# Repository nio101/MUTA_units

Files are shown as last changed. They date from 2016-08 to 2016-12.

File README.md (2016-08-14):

# MUTA_units
An open source home automation solution for hobbyists and makers

## customizing the firmwares before flashing

In the **MPLAB IPE**, activate *Setting/advanced mode*, open the firmware/.hex file you want to customize, and then select *View/show memory*.
On the *Operate* tab, you'll have a memory view window. Skip to the end of the memory and you fill view the constants you can edit inline before flashing:
* static_encryption_key @ 0x01FFEC (8 bytes)
* make/model @ 0x01FFF4 (2 bytes)
* unit_uid @ 0x01FFF6 (2 bytes)
You can then use the *view/fill memory* dialog to modify those values and check the modifications on the memory view afterwards.
*important: due to Endianness, the first and second bytes are swapped for each memory value, so you should input for example 0x0201@0x01FFF4 to get a 01 model and a 02 make*
*remark: This manual process could be done in a much easier way with the hexmate util, but my first tries weren't successfull and I couldn't spend more time on it.*

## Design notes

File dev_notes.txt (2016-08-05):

questions à adresser...

* quand un operateur disconnecte et revient, un scout peut lui envoyer un message sans reinit, mais l'operateur ne peut pas lui répondre...
=> si un autre scout utilise la même adresse dans le nouveau réseau que le scout qui est encore dans l'ancien, il va se fait passer
pour lui -> toujours transmettre l'UID et l'utiliser comme réel identifiant
L'adresse locale est juste stockée pour pouvoir communiquer avec lui, mais on transmet aussi en retour l'UID et chaque scout vérifie que c'est bien pour lui avant d'interpréter.
résumé: utiliser l'UID pour valider les messages dans les deux sens, la short address ne sert que d'alias
=> est-ce qu'on ne pourrait pas directement utiliser la long address[4]==myMODEL+myUID ?
ce serait l'idéal...
=> UnicastAddress an long adress ?

PacketLQI... == qualité, à exploiter, en complément de RSSI==puissance du signal

implémenter une commande au niveau du PAN qui permet de dumper le tableau des connections et checker les infos disponibles
dans le cas normal + cas d'erreurs (ex.: PAN remonte le réseau et recoit un message d'un scout toujours dans l'ancien réseau)

est-ce que active scan result contient aussi des end devices ? on dirait puisqu'il y a l'option sleep dans les flags de résultat...
faire le test (il faut 2 scouts!)
Si oui, limiter la connection aux devices PAN/coordinators

Implémenter un scout sur l'ancien proto d'opérateur et un PAN sur le nouveau...
=> dumper les tables de scan et les tables de connection
pui ajouter 2 coordinators (cartes protos) et le (vrai) scout
=> check tables et des différents cas/tests déco/reco, etç...

Mettre un ConnectionMode(DISABLE_ALL_CONN) sur les scouts et end devices
=> ils ne répondront pas aux active scan et aux demandes de connection

------------------------------------------------------------------------------
Liste des fonctions de l'API OUIOUI:
====================================
bool MiApp_ProtocolInit(FALSE) // false for networkfreezer/nvm use

MiApp_NoiseDetection	=> scan for noise/nergy or porteuse (PAN)

MiApp_SearchConnection => scan for existing networks

bool MiApp_SetChannel(channel)

MiApp_ConnectionMode => if device responding to connections/active scans ?

bool MiApp_StartConnection(START_CONN_DIRECT, 0,0)	// start a network

MiApp_EstablishConnection(ScanIndex, MODE_DIRECT)	// join a network through a PAN or coordinator

MiApp_FlushTx() => vide le buffer d'envoi / reset
MiApp_WriteData(byte) => ajoute un octet utilise au message à envoyer

* 3 choix pour l'envoi:
- broadcast => all devices receive the message
- unicast with shortaddress
- unicast with longaddress

MiApp_Broadcast(Sec_enabled)
MiApp_UnicastConnection(ConnectionIndex, Sec_enabled)
MiApp_UnicastAddress(*address, bool IsLongAddress, bool Sec_enabled)

MiApp_MessageAvailable() -> test if new message has been received

MiApp_DiscardMessage() -> flush the received message

MiApp_RemoveConnection(ConnectionIndex)

MiApp_TransceiverPowerStat(POWER_STATE_SLEEP/POWER_STATE_WAKEUP) -> put the MRF89XA to sleep/wake it up

// channel hopping / frequency agility
// prevent noise problems + hack is more difficult

MiApp_InitChannelHopping(channelmap)

for sleeping devices which didn't see it:
MiApp_ResyncConnection(connections index, channelmap)
------------------------------------------------------------------------------
SCAN CONNECTIONS RESULT:

    typedef struct
    {
        uint8_t		Channel;                        // Operating Channel of the PAN
        uint8_t        Address[MY_ADDRESS_LENGTH];     // Responding device address
        API_UINT16_UNION    PANID;                          // PAN Identifier
        uint8_t       RSSIValue;                      // RSSI value for the response
        uint8_t        LQIValue;                       // LQI value for the response
        union
        {
            uint8_t        Val;
            struct
            {
                uint8_t    Role:		2;              // Role of the responding device in the PAN
                uint8_t    Sleep:		1;              // Whether the responding device goes to sleep when idle
                uint8_t    SecurityEn:	1;              // Whether the responding device is capable of securing the data
                uint8_t    RepeatEn:	1;              // Whether the responding device allow repeat
                uint8_t    AllowJoin:	1;              // Whether the responding device allows other device to join
                uint8_t    Direct:		1;              // Whether the responding device in radio range or through a repeater
                uint8_t    altSrcAddr: 1;              // Whether the Address is alternative network address or permanent address
            } bits;
        } Capability;
    } ACTIVE_SCAN_RESULT;

    extern ACTIVE_SCAN_RESULT ActiveScanResults[ACTIVE_SCAN_RESULT_SIZE];
------------------------------------------------------------------------------
CONNECTIONS:

    typedef union __CONNECTION_STATUS
    {
        uint8_t Val;
        struct _CONNECTION_STAUTS_bits
        {
            uint8_t RXOnWhenIdle       :1;     //1 = transceiver always on, 0 = transceiver sleeps when idle
            uint8_t directConnection   :1;     //1 = can talk to this device directly, 0 = must route to this device
            uint8_t longAddressValid   :1;     //1 = long address valid, 0 = long address unknown
            uint8_t shortAddressValid  :1;     //1 = short address valid, 0 = short address unknown
            uint8_t FinishJoin         :1;     //1 = already finish joining procedure, 0 = in the process of join
            uint8_t isFamily           :1;     //1 = family member (parent/child), 0 = not family
            uint8_t filler             :1;
            uint8_t isValid            :1;     //1 = this entry is valid, 0 = this entry is not valid
        } bits;   
    } CONNECTION_STATUS;

typedef struct __CONNECTION_ENTRY
    {
            API_UINT16_UNION    PANID;                      // PAN Identifier of the peer device.
            API_UINT16_UNION    AltAddress;                 // Alternative address of the peer device. - SHORT ADDRESS

        uint8_t        Address[MY_ADDRESS_LENGTH];     // Permanent address of peer device - LONG ADDRESS
        
        CONNECTION_STATUS status;
        
    } CONNECTION_ENTRY;

CONNECTION_ENTRY    ConnectionTable[CONNECTION_SIZE];
------------------------------------------------------------------------------
MESSAGE RECU:

typedef struct
    {
        union
        {
            uint8_t Val;
            struct
            {
                uint8_t		broadcast:  2;      // 1: broadcast message
                uint8_t		ackReq:     1;      // 1: sender request acknowledgement in MAC.
                uint8_t		secEn:      1;      // 1: application payload has been secured
                uint8_t		repeat:     1;      // 1: message received through a repeater
                uint8_t		command:    1;      // 1: message is a command frame
                uint8_t        srcPrsnt:   1;      // 1: source address present in the packet
                uint8_t        altSrcAddr: 1;      // 1: source address is alternative network address
            } bits;
        }  flags;

        API_UINT16_UNION    SourcePANID;                // PAN Identifier of the sender
        uint8_t		*SourceAddress;             // pointer to the source address
        uint8_t		*Payload;                   // pointer to the application payload
        uint8_t		PayloadSize;                // application payload length
        uint8_t		PacketRSSI;                 // RSSI value of the receive message
        uint8_t 	PacketLQI;                  // LQI value of the received message

    } RECEIVED_MESSAGE;
------------------------------------------------------------------------------
operator:
=========
1) uint8_t BestChannel = MiApp_NoiseDetection(BASIC_CHANNELS_TEST, 14, NOISE_DETECT_ENERGY, &noise_level);
2) MiApp_SetChannel(BestChannel)
3) MiApp_ConnectionMode(ENABLE_ALL_CONN);
4) MiApp_StartConnection(START_CONN_DIRECT, 0, 0);
5) if(MiApp_MessageAvailable())
        {	... }
6) MiApp_UnicastAddress(&shortaddress, false, false)
        	
scout:
======
1) scanresult = MiApp_SearchConnection(14, COMPLETE_CHANNELS_TEST);
2) MiApp_EstablishConnection(best_candidate, CONN_MODE_DIRECT);
3) MiApp_UnicastAddress(&shortaddress, false, false)
4) if(MiApp_MessageAvailable())
            {
                // message received
                //if(rxMessage.Payload[0] == 0x13 && rxMessage.Payload[1] == 0x37)
                counter = rxMessage.Payload[2];
                MiApp_DiscardMessage();
            	break;
            }

repeater:
=========

1) MiApp_SearchConnection(14, COMPLETE_CHANNELS_TEST);
2) MiApp_ConnectionMode(ENABLE_ALL_CONN);
3) MiApp_EstablishConnection(j, CONN_MODE_DIRECT);
4) if(MiApp_MessageAvailable())
		MiApp_DiscardMessage();

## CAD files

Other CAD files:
src/18F27J53_op_basecamp/dev_18F27J53_operator_basecamp.X/dist/18F27J53/production/dev_18F27J53_operator_basecamp.X.production.obj
src/18F27J53_op_basecamp/dev_18F27J53_operator_basecamp.X/l.obj
src/18F27J53_op_relay/dev_18F27J53_operator_relay.X/dist/16F27J53/production/tests_conso.X.production.obj
src/18F27J53_op_relay/dev_18F27J53_operator_relay.X/dist/18F27J53/production/dev_18F27J53_operator_relay.X.production.obj
src/18F27J53_op_relay/dev_18F27J53_operator_relay.X/l.obj
src/18F27J53_scout_dormant/dev_18F27J53_scout_dormant.X/dist/18F27J53/production/dev_18F27J53_scout_dormant.X.production.obj
src/18F27J53_scout_dormant/dev_18F27J53_scout_dormant.X/l.obj

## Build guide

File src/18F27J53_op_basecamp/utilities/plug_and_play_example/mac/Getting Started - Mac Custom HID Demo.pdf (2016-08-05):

# Mac Custom HID Demo

### Contents

Xcode and Objective-C

Interface Builder

HID Framework

Application Overview

Graphical User Interface Overview

Common Pitfalls

### Xcode and Objective-C

The Mac Custom HID Demo application was created using Xcode, Apple’s IDE that comes pre-packaged with Mac OS X operating systems. In this example, the Cocoa application programming interface (API) is used. Cocoa is one of Apple’s APIs available for Mac OS X, and uses the Objective-C programming language. Objective-C is an object-oriented programming language that is built on top of C that is used primarily by Apple. For more information on Objective-C and a good starting point for beginners, check out Apple’s guide to Learning Objective-C. (http://developer.apple.com/library/ios/)

### Interface Builder

The Interface Builder application is part of Xcode, and also comes pre-packaged with MAC OS X operating systems. It is used to design graphical user interfaces (GUIs), and was used to design the GUI in this example. A simple step-by-step tutorial showing how to use Xcode with the Interface Builder is available in the Mac OS X Reference Library called the Cocoa Application Tutorial. (http://developer.apple.com/library/mac/)

### HID Framework

For HID class USB communication between a Mac and a connected device, Cocoa uses an API called the HID Manager that is part of the I/O Kit framework. In order to use the HID Manager in your project, the I/O Kit framework needs to be added. Follow these steps to do this:

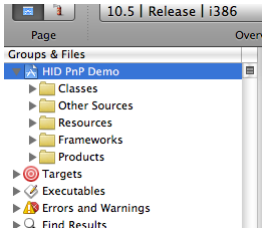
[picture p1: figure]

1. After creating your project, expand your project in the “Groups & Files” panel to show the Frameworks subfolder.

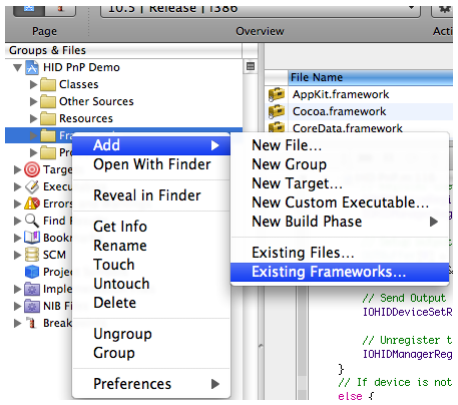
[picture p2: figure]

2. Right click on the Frameworks subfolder (command-click) and select Add > Existing Frameworks…

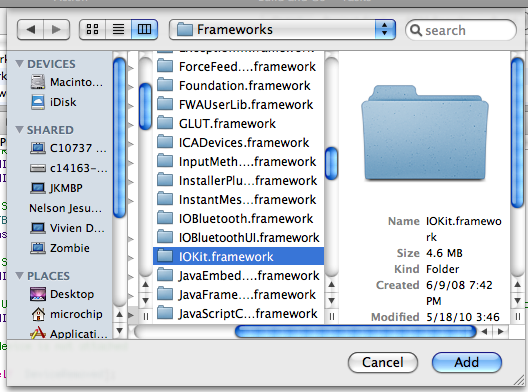
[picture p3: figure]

3. Scroll down and select IOKit.framework and click the Add button.

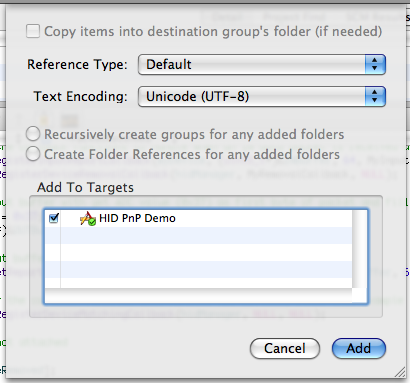
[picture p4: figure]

4. A verification window will be shown. Click the Add button again.

Now the HID Manager can be used in your project. To make the functions within the HID Manager API available make sure to use #import. #import is similar to #include, but ensures a header is included only once in a source file. For this example, the HID_PnP class uses the following:

#import <IOKit/hid/IOHIDManager.h>

This API is implemented in C, but because Objective-C is a strict superset of C, the API can be used interchangeably within Objective-C code. The HID Manager handles all enumerated HID class devices and allows access to their properties, notification for when a new device is enumerated or an existing devices is removed, and communication between host and device. For more detailed information about the HID Manager, both Technical Note TN2187 (http://developer.apple.com/library/mac/#technotes/tn2007/tn2187.html) and the HID Class Device Interface Guide (http://developer.apple.com/library/mac/#documentation/DeviceDrivers/Conceptual/HID/intro/intro.html) are good sources.

### Application Overview

Overall, the same GUI and functionality is used as Microchip’s Plug and Play example for Windows. The pushbutton status and potentiometer values are transmitted from the device to the host, and when the toggle LED(s) button is pressed in the app window, the LEDs on the device are toggled. The demo also supports hot plugging the device and detects when the device is removed.

Because the demo is written in a different language and is on a different operating system, the code layout is not exactly the same. This is a brief overview of how the application works. There are two objective-C classes that behave similarly to a C++ class or Java class, the HID_PnP class and the DemoApp class.

The HID_PnP class handles the communication with the Custom HID Device. There is an instance of a HID Manager as well as an instance of a HID Device within the class. When a device is attached, the HID Device instance holds the information about that device. The HID Manager is always running and is initialized with a few C callback functions for when a device is attached, removed, or when it sends data. These functions are called when one of these events occurs. Otherwise it returns to the run loop that is running the application.

The DemoApp class handles the application window created in the interface builder. It updates what is seen in the window depending on what information is sent from the device. There is an object of the HID_PnP class that is part of the DemoApp class. This object handles the communication and is polled every 15 ms (~60 Hz) by the DemoApp Class to update its window. It also notifies the HID_PnP object when the Toggle LED(s) button has been pressed.

The run loop for the entire application is shared by HID communication, GUI updates, and the button in the GUI window. This means that all of these are in one thread, which is different from the windows application. The windows application has two threads, one for updating the GUI and waiting for a button press, and another for HID communication. The windows thread that handles the HID communication communicates asynchronously with the device. This means that the functions called are blocking, so while the host is communicating the device, any other code is halted from executing on the same thread. For the mac, the communication is synchronous, which means that the functions are non-blocking and perform similar to an interrupt on a microcontroller. This means that the application can return to the run loop and perform other tasks such as updating the gui while it waits for the device to respond to the host.

### Graphical User Interface Overview

Below is what the application window looks like when the device is disconnected. The progress bar and labels are greyed out, the toggle LED button is disabled, the text box at the top states that the device is not attached, and the pushbutton status is unknown.

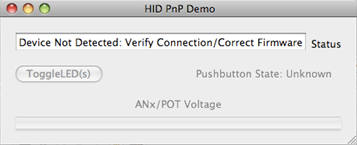
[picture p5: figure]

Next is what the application window looks like when the device is connected. The progress bar begins to show the value of the potentiometer, the labels are no longer greyed out, the toggle LED button is no longer disabled, the text box at the top states that the device is attached, and the pushbutton state is either pressed or unpressed.

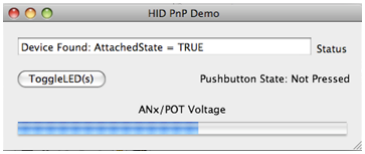
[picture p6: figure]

### Common Pitfalls

Mixing Objective-C with C
There are some common pitfalls that one might run into while developing USB code for the mac. For instance, if an application GUI is preferred, then the interface builder is the easiest way to create the GUI. In order to use the interface builder, objective-C should be used. However, some APIs are in C or C++, which means that mixing the two languages is required. It is possible to have C functions inside of an objective C class.

This example shows how that is possible. The C callback functions for the HID Manager are part of the HID_PnP class. However, since they are C functions, they do not have access to the variables inside of the class nor can they have objects including the instance of the HID_PnP class which is referred to as “self” inside of the class. Because “self” can’t be used, accessing the class methods is difficult (which is called sending a message in Objective-C). To go around this, a self referencing void pointer is created as a global variable in the source file of the HID_PnP class. This pointer points to the instance of the class itself in the init method – the class initialization function for HID_PnP. Because of Objective-C’s ability for dynamic typing (see Objective-C overview), the void pointer can act as the self reference and can access the class’s methods.

Additionally, because some functions are in C, they are unable to take objects as arguments. To go around this, there are definitions of structs within the API that are the same size as objects that are needed as arguments. So, if writing in objective-C type-casting can be used to go between objects and structs.

Mouse Click Events
For each thread used in an application there is a run loop. A run loop is (usually) an infinite loop that runs certain actions over and over again. However, if one of these actions is blocking (meaning it waits for an event to complete before returning to the run loop) then it can create a delay for other actions within the same run loop. The usual solution to this problem is to separate the blocking actions into separate threads. This is not always the case, though.

A mouse click event is when a mouse click occurs in the window that can be blocking to the application, for example clicking and holding down a button, or dragging or resizing the window. These events can disrupt the workflow of the application. Instead of creating an additional thread so that all other functions can run on an additional run loop, the functions can be within the same run loop but with a certain run mode. When you add an action to a run loop, you add it with a mode. Typically the default mode is used (kCFRunLoopDefaultMode). However, if you add the action to the run loop with the event tracking mode (NSEventTrackingRunLoopMode), then it will still be able to run while a mouse click event is occurring. Therefore, an action needs to be added to the run loop twice, once with the default mode, and second with the event tracking mode. For this example there are three actions and one run loop. The mouse click event, which is when the button is being pressed or the window is being resized, the timer that updates the GUI with the HID communication from the device, and the HID Manager which handles the HID communication. Both the timer and the HID Manager were added to the run loop in both modes, so they won’t be disrupted by a mouse click event.

CPU Usage
As stated in the previous section, a run loop contains actions that are continuously repeated. If these actions utilize the CPU fully, then your application can end up hogging most of the CPU resources. If the actions only need to be performed periodically, then a great way to free up CPU resources is to suspend the thread’s execution for a period of time. This can be done with any of the three sleep subroutines: sleep or nsleep. The sleep function has the following form:

unsigned int sleep(unsigned int seconds);

The thread is suspended for the specified amount of seconds or until a signal is received. It returns a zero if the requested time has elapsed, or the number of seconds that are left if a signal is received. The nsleep function takes in two timespec structs and has the following form:

int nsleep(const struct timespec *req, struct timespec *rem);

And the timespec struct has the following form:

struct timespec {
time_t tv_sec; | /* seconds */
long | tv_nsec; | /* nanoseconds */
};

The nsleep function sleeps for the specified amount of time given in *req or until a signal is received. It returns 0 after completing the amount of time or -1 if a signal has been received. If a signal has been received, the remaining time is written to the struct that *rem is pointing to.

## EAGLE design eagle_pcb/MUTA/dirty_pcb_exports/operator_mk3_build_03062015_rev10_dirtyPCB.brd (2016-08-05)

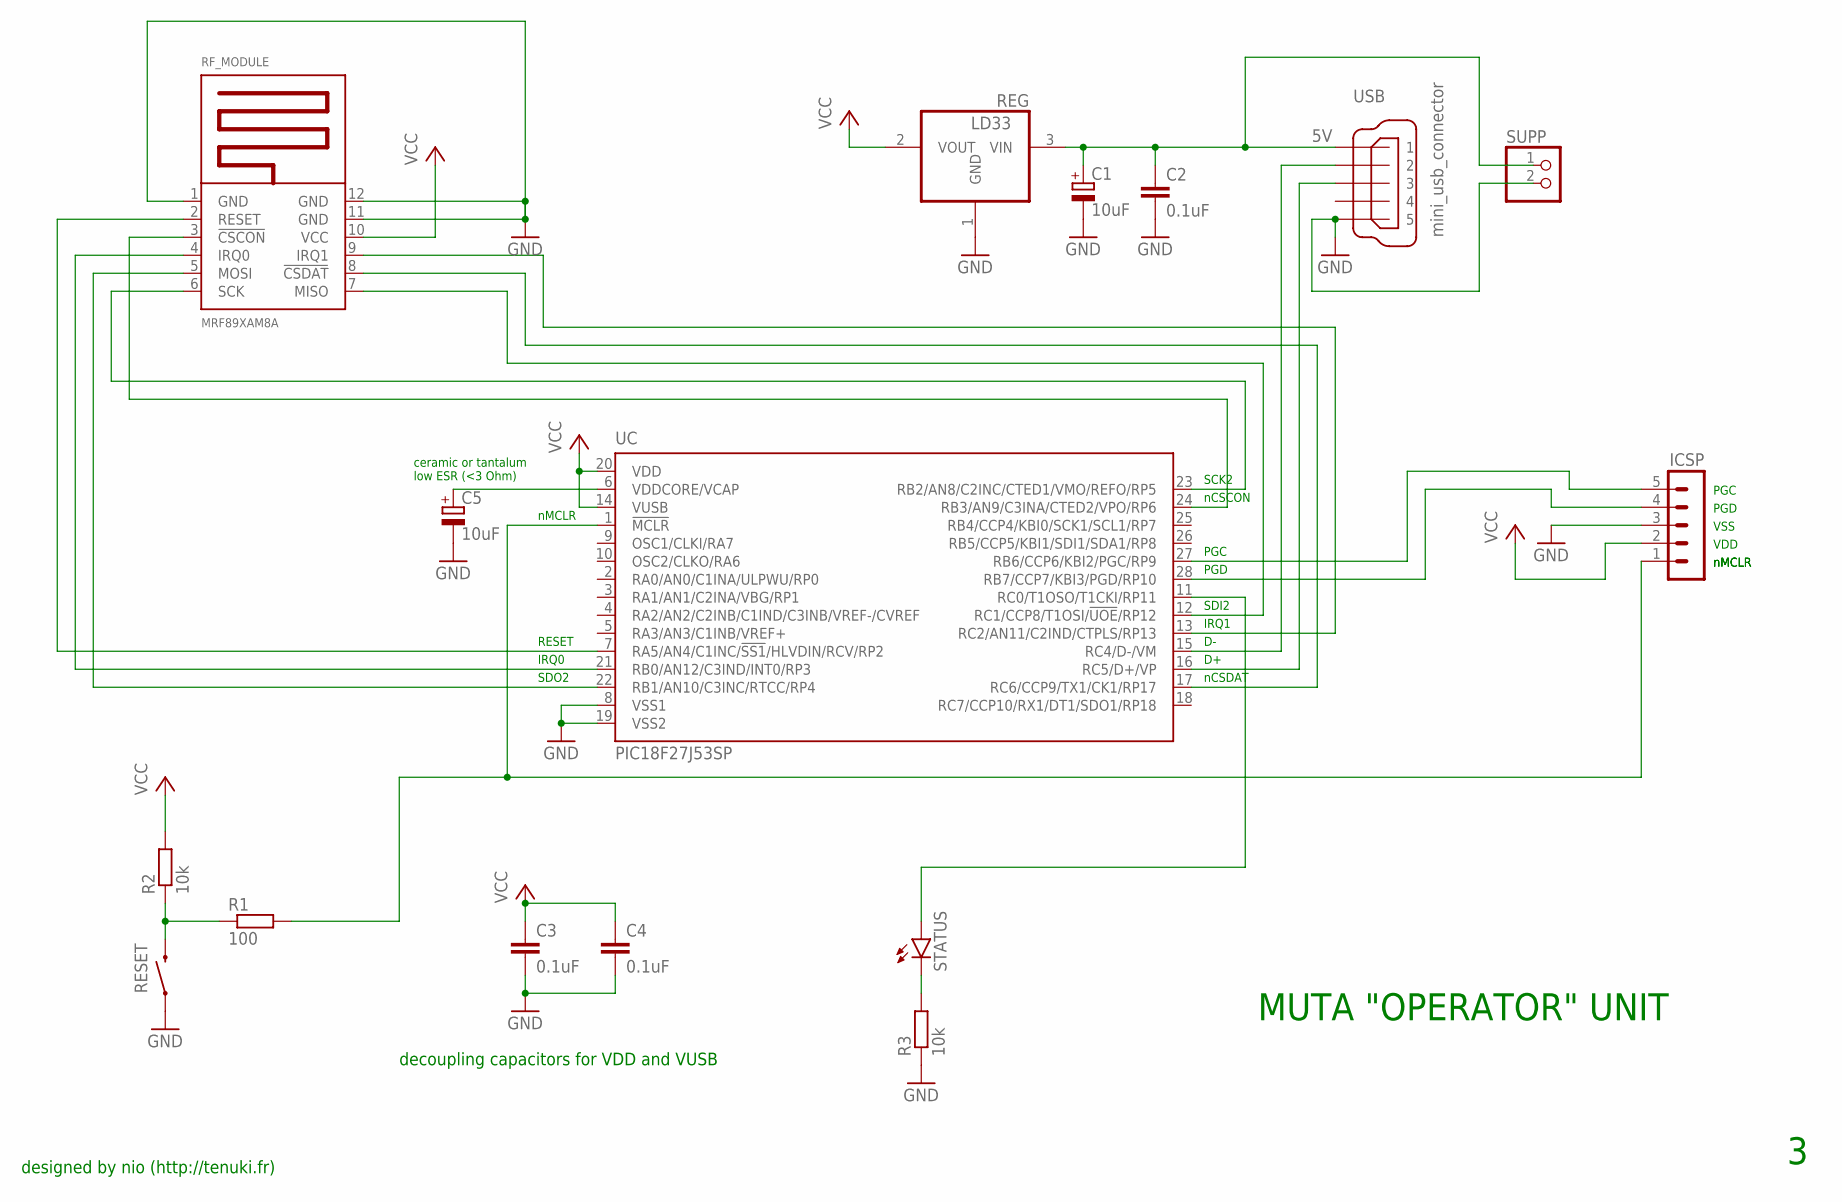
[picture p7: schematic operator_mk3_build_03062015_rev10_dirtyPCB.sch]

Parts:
C1: 10uF; TT5D6
C2, C3, C4: 0.1uF; C050-025X075
C5: 10uF; C/6032-28R
ICSP: MA05-1
R1: 100; 0207/10
R2: 10k; 0207/10
R3: 10k; 0207/2V
REG: LD33; SOT223; MPN LD33
RESET: SWITCH-MOMENTARY-2PTH; TACTILE-PTH
RF_MODULE: MRF89XAM8A; MRF89XAMXA
STATUS: LED5MM
SUPP: PINHD-1X2; 1X02
UC: PIC18F27J53SP; DIL28-3
USB: mini_usb_connector; UX60-MB-5ST

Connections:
5V: C1.+, C2.1, REG.3 (VIN), SUPP.1, USB.1
GND: C1.-, C2.2, C3.2, C4.2, C5.-, ICSP.3, R3.1, REG.1 (GND), RESET.1, RF_MODULE.1 (GND), RF_MODULE.11 (GND), RF_MODULE.12 (GND), SUPP.2, UC.8 (VSS1), UC.19 (VSS2), USB.5
unnamed: UC.15 (RC4/D-/VM), USB.2
unnamed: UC.16 (RC5/D+/VP), USB.3
unnamed: ICSP.1, R1.2, UC.1 (!MCLR)
unnamed: C5.+, UC.6 (VDDCORE/VCAP)
unnamed: R1.1, R2.1, RESET.3 (2)
unnamed: ICSP.4, UC.28 (RB7/CCP7/KBI3/PGD/RP10)
unnamed: ICSP.5, UC.27 (RB6/CCP6/KBI2/PGC/RP9)
unnamed: RF_MODULE.2 (RESET), UC.7 (RA5/AN4/C1INC/!SS1!/HLVDIN/RCV/RP2)
unnamed: RF_MODULE.6 (SCK), UC.23 (RB2/AN8/C2INC/CTED1/VMO/REFO/RP5)
unnamed: R3.2, STATUS.K (C)
unnamed: STATUS.A, UC.11 (RC0/T1OSO/T1CKI/RP11)
unnamed: RF_MODULE.7 (MISO), UC.12 (RC1/CCP8/T1OSI/!UOE!/RP12)
unnamed: RF_MODULE.3 (!CSCON), UC.24 (RB3/AN9/C3INA/CTED2/VPO/RP6)
unnamed: RF_MODULE.5 (MOSI), UC.22 (RB1/AN10/C3INC/RTCC/RP4)
unnamed: RF_MODULE.4 (IRQ0), UC.21 (RB0/AN12/C3IND/INT0/RP3)
unnamed: RF_MODULE.9 (IRQ1), UC.13 (RC2/AN11/C2IND/CTPLS/RP13)
unnamed: RF_MODULE.8 (!CSDAT), UC.17 (RC6/CCP9/TX1/CK1/RP17)
VCC: C3.1, C4.1, ICSP.2, R2.2, REG.2 (VOUT), RF_MODULE.10 (VCC), UC.14 (VUSB), UC.20 (VDD)

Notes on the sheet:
MUTA "OPERATOR" UNIT
decoupling capacitors for VDD and VUSB
ceramic or tantalum low ESR (<3 Ohm)
nMCLR
VDD
VSS
PGD
PGC
SCK2
SDI2
SDO2
IRQ1
IRQ0
nCSDAT
nCSCON
RESET
designed by nio (http://tenuki.fr)

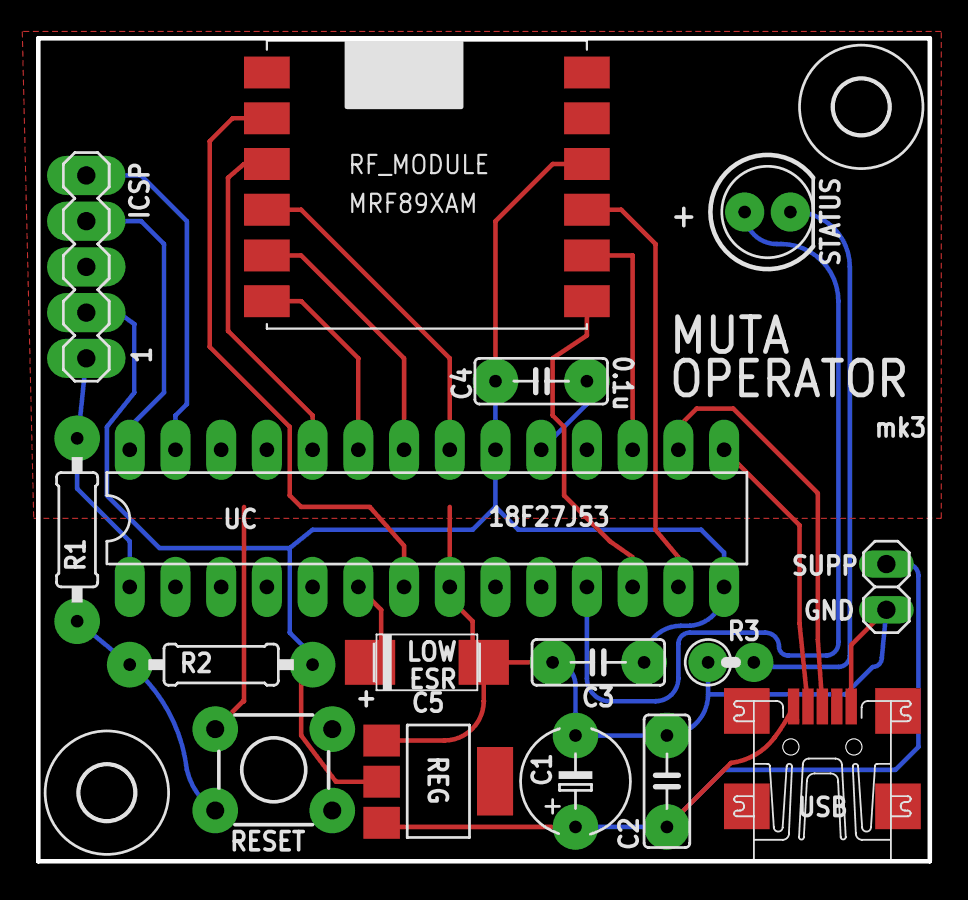
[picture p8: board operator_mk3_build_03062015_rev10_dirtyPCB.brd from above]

Board: 2 copper layers, 49.5 x 45.7 mm, 18 parts (0 on the bottom side), 20 nets.

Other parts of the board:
U$1, U$4: 3,0

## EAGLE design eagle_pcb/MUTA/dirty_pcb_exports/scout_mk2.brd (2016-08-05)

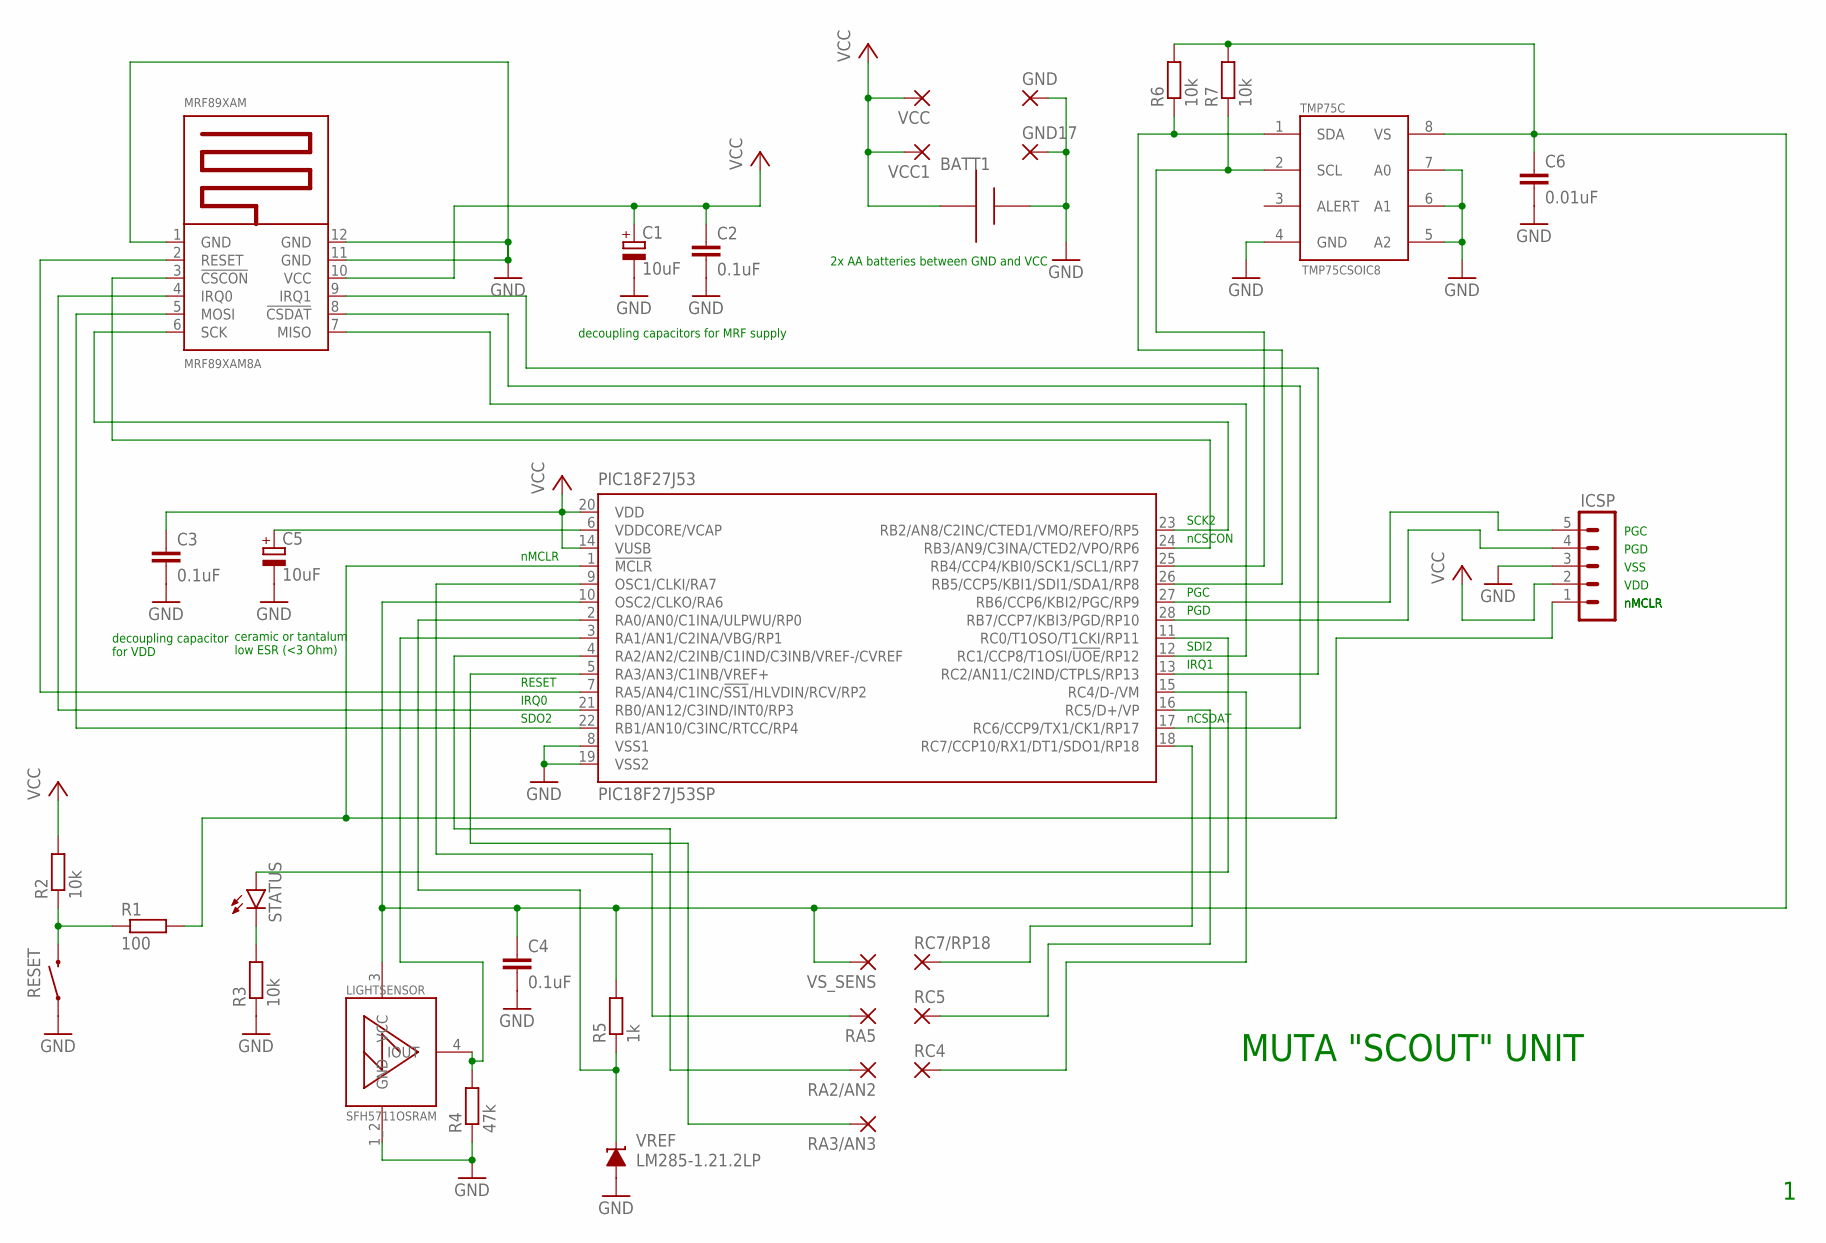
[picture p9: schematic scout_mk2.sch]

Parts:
BATT1: AAA; 2XAAA
C1: 10uF; TT5D6
C2, C3, C4: 0.1uF; C050-025X075
C5: 10uF; C/6032-28R
C6: 0.01uF; C050-025X075
GND, GND17: 3,81/1,1
ICSP: MA05-1
LIGHTSENSOR: SFH5711OSRAM; SFH5711
MRF89XAM: MRF89XAM8A; MRF89XAMXA
PIC18F27J53: PIC18F27J53SP; DIL28-3
R1: 100; 0207/10
R2, R6, R7: 10k; 0207/10
R3: 10k; 0207/2V
R4: 47k; 0207/10
R5: 1k; 0207/10
RA2/AN2, RA3/AN3, RA5: 3,81/1,1
RC4, RC5, RC7/RP18: 3,81/1,1
RESET: SWITCH-MOMENTARY-2PTH; TACTILE-PTH
STATUS: LED1206; LED-1206
TMP75C: TMP75CSOIC8; SOIC8
VCC, VCC1: 3,81/1,1
VREF: LM285-1.21.2LP; LP_O-PBCY-W3
VS_SENS: 3,81/1,1

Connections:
GND: BATT1.P$1 (+), C1.-, C2.2, C3.2, C4.2, C5.-, C6.2, GND.1, GND17.1, ICSP.3, LIGHTSENSOR.1_2 (GND), MRF89XAM.1 (GND), MRF89XAM.11 (GND), MRF89XAM.12 (GND), PIC18F27J53.8 (VSS1), PIC18F27J53.19 (VSS2), R3.1, R4.1, RESET.1, TMP75C.4 (GND), TMP75C.5 (A2), TMP75C.6 (A1), TMP75C.7 (A0), VREF.3 (A)
unnamed: LIGHTSENSOR.4 (IOUT), PIC18F27J53.3 (RA1/AN1/C2INA/VBG/RP1), R4.2
unnamed: ICSP.1, PIC18F27J53.1 (!MCLR), R1.2
unnamed: C5.+, PIC18F27J53.6 (VDDCORE/VCAP)
unnamed: R1.1, R2.1, RESET.3 (2)
unnamed: ICSP.4, PIC18F27J53.28 (RB7/CCP7/KBI3/PGD/RP10)
unnamed: ICSP.5, PIC18F27J53.27 (RB6/CCP6/KBI2/PGC/RP9)
unnamed: PIC18F27J53.2 (RA0/AN0/C1INA/ULPWU/RP0), R5.1, VREF.2 (C)
unnamed: MRF89XAM.2 (RESET), PIC18F27J53.7 (RA5/AN4/C1INC/!SS1!/HLVDIN/RCV/RP2)
unnamed: MRF89XAM.6 (SCK), PIC18F27J53.23 (RB2/AN8/C2INC/CTED1/VMO/REFO/RP5)
unnamed: PIC18F27J53.26 (RB5/CCP5/KBI1/SDI1/SDA1/RP8), R6.1, TMP75C.1 (SDA)
unnamed: PIC18F27J53.25 (RB4/CCP4/KBI0/SCK1/SCL1/RP7), R7.1, TMP75C.2 (SCL)
unnamed: PIC18F27J53.9 (OSC1/CLKI/RA7), RA5.1
unnamed: R3.2, STATUS.C
unnamed: PIC18F27J53.11 (RC0/T1OSO/T1CKI/RP11), STATUS.A
unnamed: PIC18F27J53.4 (RA2/AN2/C2INB/C1IND/C3INB/VREF-/CVREF), RA2/AN2.1
unnamed: PIC18F27J53.5 (RA3/AN3/C1INB/VREF+), RA3/AN3.1
unnamed: MRF89XAM.7 (MISO), PIC18F27J53.12 (RC1/CCP8/T1OSI/!UOE!/RP12)
unnamed: MRF89XAM.3 (!CSCON), PIC18F27J53.24 (RB3/AN9/C3INA/CTED2/VPO/RP6)
unnamed: MRF89XAM.5 (MOSI), PIC18F27J53.22 (RB1/AN10/C3INC/RTCC/RP4)
unnamed: MRF89XAM.4 (IRQ0), PIC18F27J53.21 (RB0/AN12/C3IND/INT0/RP3)
unnamed: MRF89XAM.9 (IRQ1), PIC18F27J53.13 (RC2/AN11/C2IND/CTPLS/RP13)
unnamed: MRF89XAM.8 (!CSDAT), PIC18F27J53.17 (RC6/CCP9/TX1/CK1/RP17)
unnamed: PIC18F27J53.18 (RC7/CCP10/RX1/DT1/SDO1/RP18), RC7/RP18.1
unnamed: PIC18F27J53.16 (RC5/D+/VP), RC5.1
unnamed: PIC18F27J53.15 (RC4/D-/VM), RC4.1
unnamed: C4.1, C6.1, LIGHTSENSOR.3 (VCC), PIC18F27J53.10 (OSC2/CLKO/RA6), R5.2, R6.2, R7.2, TMP75C.8 (VS), VS_SENS.1
VCC: BATT1.P$2 (-), C1.+, C2.1, C3.1, ICSP.2, MRF89XAM.10 (VCC), PIC18F27J53.14 (VUSB), PIC18F27J53.20 (VDD), R2.2, VCC.1, VCC1.1

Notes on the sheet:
MUTA "SCOUT" UNIT
decoupling capacitor for VDD
ceramic or tantalum low ESR (<3 Ohm)
nMCLR
VDD
VSS
PGD
PGC
SCK2
SDI2
SDO2
IRQ1
IRQ0
nCSDAT
nCSCON
RESET
decoupling capacitors for MRF supply
2x AA batteries between GND and VCC

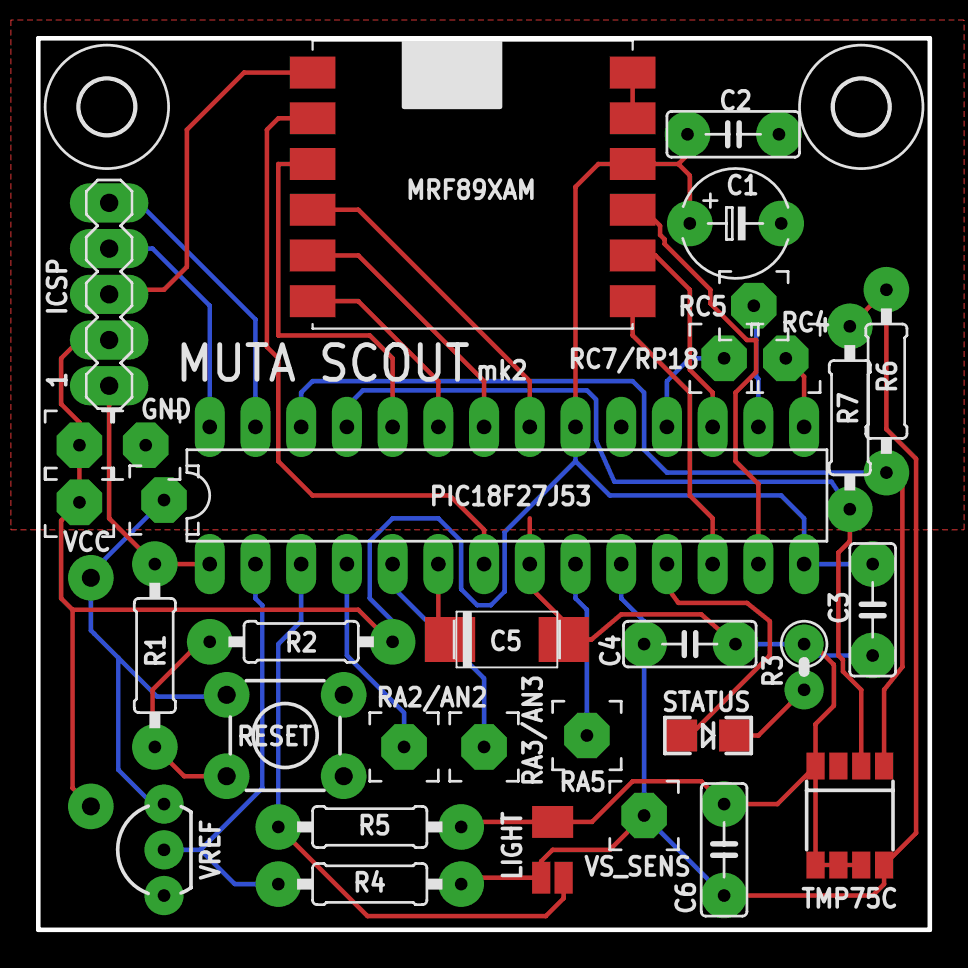
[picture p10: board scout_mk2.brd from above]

Board: 2 copper layers, 49.5 x 49.5 mm, 35 parts (0 on the bottom side), 28 nets.

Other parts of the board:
U$2, U$3: 3,0

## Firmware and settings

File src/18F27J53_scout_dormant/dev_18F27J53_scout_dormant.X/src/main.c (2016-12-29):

/*
 * MUTA scout / dormant - r2 (MUTA v01) - 12/2016
 * 
 * Main source code: copyright (2015-2016) Nicolas Barthe,
 * distributed as open source under the terms
 * of the GNU General Public License (see COPYING.txt)
 * 
 * USB and MIWI original code: copyright Microchip.
 * 
*/

#include <xc.h>         // should compile with XC8 v1.35 + legacy PLIB v2.00
#include <stdint.h>     // remember: you must install manually legacy plib
#include <i2c.h>        // those since XC8 v1.35 doesn't include plib anymore
#include <rtcc.h>
#include <timers.h>
#include <pwm.h>
#include <math.h>
#include "18F27J53/system.h"
#include "18F27J53/system_config.h"
#include "18F27J53/symbol.h"
#include "miwi/miwi_api.h"
#include "miwi/drv_mrf_miwi_89xa.h"
#include "../../../muta/muta_messages.h"

/* miwi config is configured through the following files:
      config_89xa.h: TX power, bitrate...
      miwi_config.h: Miwi role/options

the initial output power is determined statically
by the value of TX_POWER set in config_89xa.h.
Current config: 1dBm => 1.2mW

Remember: Miwi stack uses TIMER1

*/
/* config words start @0x01FFF8
let's put some const at the end of flash memory:
    model of the unit (00: operator, 01:scout, 02:enforcer...)
    + make of the unit (1 for mk1, 2 for mk2...) */
const uint8_t myMUTA_version @ 0x01FFF2 = 0x01; // MUTA protocol version
const uint8_t myMODEL @ 0x01FFF4 = 0x01; // scout
// Unique ID used to identify the unit
const uint8_t myUID[2] @ 0x01FFF6 = { 0x00, 0x02 };   // uid
/* those info are mapped @ 0x01FFF4 and 0x01FFF6, and can then be modified
 * without recompiling the firmware, if needed (using the proper tool) */
extern uint8_t myLongAddress[4];    // equal to myMODEL+myUID
                                    // done at the beginning of main()

// this is the 64bit key that will be used for encryption/decryption
// !!!it should be the same for every unit!!!
// algo: XTEA64 + CCM_16
// the key is mapped @ 0x01FEC and can then be modified without recompiling
// the firmware, if needed (using the proper tool)
const unsigned char StaticSecurityKey[8] @ 0x01FFEC = { 0x00, 0x01, 0x02, 0x03, 0x04, 0x05, 0x06, 0x07  };
unsigned char mySecurityKey[8];
/* note: mySecurityKey will be initialized with StaticSecurityKey
 * then mySecurityKey[2] and mySecurityKey[6] will be replaced by
 * random values generated for each network session, and returned through NETWORK_REGISTER */

/* Memory mapping of myMODEL, myUID and mySecurityKey:
    myMODEL[2] @ 0x01FFF4
    myUID[2] @ 0x01FFF6
    mySecurityKey[8] @ 0x01FFEC        
=> allow the use of HEXMATE (command line utility that comes with MPLABX)
to modify those value without recompiling the firmware
ex.: HEXMATE source.hex -FILL=0xBEEF@0x1000 -Odest.hex */
// Possible channel numbers are from 0 to 31
// channels 0,4,8,12,16,20,24,28 (~22sec max))
#define MUTA_CHANNELS      0x11111111
//#define MUTA_CHANNELS      0x01010101   // channel 0,8,16,24 only
//#define MUTA_CHANNELS      0x00000001   // channel 0 only

#define MINIMAL_RSSI     35
#define MUTA_PANID   0x1337

#define MAX_CONSECUTIVE_FAILS   3

// to use the internal RTCC as a timer
// with frequency==multiples of 1min, default @1min
#define DEFAULT_UPDATE_FREQUENCY    1
volatile bool timer_flag = false;
volatile uint8_t timer_count = DEFAULT_UPDATE_FREQUENCY;

// Variables / values
const char POWER_LABEL[] = "Pwr";
uint8_t m_power;
const char UPTIME_LABEL[] = "Upt";
volatile float m_uptime_days = 0;   // updated every minute
const char UPDATE_FREQUENCY_LABEL[] = "UpF";
volatile uint8_t m_update_frequency = DEFAULT_UPDATE_FREQUENCY;
const char FAILEDMSG_LABEL[] = "FlM";
uint8_t consecutive_fails = 0;
unsigned long m_failed_messages = 0;
unsigned long m_sent_messages = 0;
const char BATTERY_VOLTAGE_LABEL[] = "VBa";
float m_battery_voltage = 0.0;
const char LIGHT_LEVEL_LABEL[] = "Lit";
uint8_t m_light_level = 0;
const char TEMPERATURE_LABEL[] = "Tmp";
float m_temperature = 0.0;

bool Pwr_updated = false;
bool UpF_updated = false;

// TinyPack encoding stuff
uint8_t m_buffer[32];
uint8_t * p_buffer;
MUTA_VARIABLE m_var;

// Main functions / helpers to keep the main code simple & clean
bool process_update_answer();
void read_sensors();
bool send_initial_update();
bool send_writables_update();
bool send_periodical_update();
void update_variable();
void timer_reset();
void RTCC_reset();
void wait_for_1_sec();
void inline sleep_and_reset();

// temp sensor I2C address
#define temp_slave_address 0b10010000

// declare the scout as a sleeping unit
#define SLEEPING_SCOUT

APP_STATE   myAppState; // track App status


// ------------------
//      main loop
// ------------------
void main() {

    SYSTEM_Initialize(); // PIC hardware setup/configuration    
    
    RTCC_reset();
    timer_reset();
        
    myAppState = STATE_INIT;

    bool result;
    // set the unique LongAddress as the result of the unique myMODEL+myUID
    myLongAddress[0] = myMUTA_version;
    myLongAddress[1] = myMODEL;
    myLongAddress[2] = myUID[0];
    myLongAddress[3] = myUID[1];
    
    // initialize the security key
    for (int x=0; x<8; x++)
        mySecurityKey[x] = StaticSecurityKey[x];
    
    MiApp_ProtocolInit(false);  // init the Miwi stack
    MiMAC_SetPower(TX_POWER);   // use max power for scan process
    
    // A) SEARCH FOR A NETWORK WITH PANID == MUTA_PANID
    //=================================================
    volatile uint8_t scanresult;
    while(1)
    {
        scanresult = MiApp_SearchConnection(8, MUTA_CHANNELS);
        if (scanresult == 0)
        {
            // no candidate found, sleep & try again + increase the 
            // default tryout frequency by 1mn, up to 10min
            if (m_update_frequency<10)
            {
                m_update_frequency++;
            }
            LATCbits.LATC0 = 0;  // turn led off
            timer_reset();
            MiApp_TransceiverPowerState(POWER_STATE_SLEEP);
#ifdef SLEEPING_SCOUT
            while (!timer_flag)
            {
                OSCCONbits.IDLEN = 0;   // specs says it should be used just before SLEEP())
                SLEEP();        // now we are sleeping            
            }
#else
            while(!timer_flag)
            {}
#endif
            MiApp_TransceiverPowerState(POWER_STATE_WAKEUP);// wake up the MRF89
            //if(MiApp_MessageAvailable()) // flush - not required here:
            //    MiApp_DiscardMessage();  // Miwi is not initialized!
            //MiWiTasks();
        }
        else
        {
            // restore the default update frequency
            m_update_frequency = DEFAULT_UPDATE_FREQUENCY;
            break;
        }
    }
    uint8_t best_RSSI = 0;
    uint8_t best_candidate;
    for(uint8_t j = 0; j < scanresult; j++)
    {   
        if (ActiveScanResults[j].RSSIValue >= best_RSSI && ActiveScanResults[j].PANID.Val == MUTA_PANID)
        {
            best_RSSI = ActiveScanResults[j].RSSIValue;
            best_candidate = j;
        }
    }
    
    // B) JOIN THE NETWORK
    //====================
    uint8_t Status = MiApp_EstablishConnection(best_candidate, CONN_MODE_DIRECT);
    if(Status == 0xFF)
    {  
        // joining network failed!
        // let's sleep 1 cycle before resetting
        myAppState = STATE_PROBLEM;
        sleep_and_reset();
    }
    MiApp_ConnectionMode(DISABLE_ALL_CONN);  // don't answer to scan or join requests
    
    // C) NETWORK_REGISTER
    //====================
#ifdef SLEEPING_SCOUT
    /* I don't use the sleeping feature of Miwi
     * - I couldn't get it to work! - but we don't need it anyway */
    result = do_NETWORK_REGISTER(&myLongAddress[0],MUTA_BOOL_TRUE);
#else
    result = do_NETWORK_REGISTER(&myLongAddress[0],MUTA_BOOL_FALSE);
#endif
    if (!result)
    {
        // auth failed!
        // let's sleep 1 cycle before resetting
        myAppState = STATE_PROBLEM;
        sleep_and_reset();
    }
    
    // force security key update on
    security_force_key_update();
    
    myAppState = STATE_READY;
    
    // D) POWER LEVEL DYNAMIC ADAPTATION
    // =================================
    m_power = adapt_power_level(TX_POWER, MINIMAL_RSSI);
    
    // E) RESET UPTIME, READ SENSORS, SEND INITIAL UPDATE
    // ==================================================
    m_uptime_days = 0;

    RTCC_reset();   // to resync it to every min from now
    
    read_sensors();  
    while (!send_initial_update())
    {
        // another failed attempt
        consecutive_fails++;
        if (consecutive_fails >= MAX_CONSECUTIVE_FAILS)
        {
            // let's sleep 1 cycle before resetting
            myAppState = STATE_PROBLEM;
            sleep_and_reset();
        }
        wait_for_1_sec();
    }
    consecutive_fails = 0;  // here we have received an UPDATE as answer to send_initial_update()
    
    // F) MAIN LOOP
    // ============
    while (true)
    {
        // F1) PROCESS RECEIVED UPDATE
        // ===========================
        process_update_answer();
                
        // F2) SLEEP/READ/SEND UPDATE
        // ==========================
        LATCbits.LATC0 = 0;  // turn led off
        MiApp_TransceiverPowerState(POWER_STATE_SLEEP);
        timer_reset();
#ifdef SLEEPING_SCOUT
            while (!timer_flag)
            {
                OSCCONbits.IDLEN = 0;   // specs says it should be used just before SLEEP())
                SLEEP();        // now we are sleeping            
            }
#else
            while(!timer_flag)
            {}
#endif
        LATCbits.LATC0 = 1;  // turn led on
        read_sensors();
        MiApp_TransceiverPowerState(POWER_STATE_WAKEUP);    // wake up the MRF89
        if(MiApp_MessageAvailable()) // flush
            MiApp_DiscardMessage();
        MiWiTasks();
        while (!send_periodical_update())
        {
            // failed attempt
            consecutive_fails++;
            if (consecutive_fails >= MAX_CONSECUTIVE_FAILS)
            {
                // let's sleep 1 cycle before resetting
                myAppState = STATE_PROBLEM;
                sleep_and_reset();
            }
            wait_for_1_sec();
        }
        consecutive_fails = 0;  // here we have received an UPDATE as answer to send_periodical_update()
    }
}


/* read update answers from PAN operator until timeout, update message empty or ack_required with variables update
 * if variables update, send_writables and wait for an update message as answer (whatever the content, the process will stop here)
 * return true if everything is normal, false if error sending/error receiving (timeout)
 */

bool process_update_answer()    // TODO
{
    uint8_t shortaddress[2];    // short address of sender
    uint8_t result = false;
    uint8_t i;

    // faire une boucle while avec sorties: update vide(true), timeout (false) ou ack_required => send_writables => attente réponse ou timeout
    // réponse => ok, on s'arrête là (true) et on discarde le message reçu (pas d'enchainement d'update requests), timeout => false
    
    while(true)
    {
        for (i=0; i<200; i++)   // check for an answer with a 10ms interval check
        {                       // within a 2sec timeframe (sec for all the update messages)
            __delay_ms(10);
            if(MiApp_MessageAvailable())
            {
                shortaddress[0] = rxMessage.SourceAddress[0];
                shortaddress[1] = rxMessage.SourceAddress[1];
                uint8_t size = rxMessage.PayloadSize;
                switch(rxMessage.Payload[0])
                {                
                    case MUTA_UPDATE: // UPDATE message
                        // if it's for me, coming from PAN operator, and empty,
                        // then stop here & return true, it's an ack
                        if ((shortaddress[0] == 0x00) && (shortaddress[1] == 0x00) && (size == 2))
                        {
                            return true;
                        }
                        // else if it's for me, coming from PAN operator, and not empty,
                        // then process it, there are updates to do
                        else if ((shortaddress[0] == 0x00) && (shortaddress[1] == 0x00) && (size > 2))
                        {
                            bool ack_required = rxMessage.Payload[1];
                            // decode the values
                            p_buffer = &rxMessage.Payload[2];
                            while ((p_buffer - &rxMessage.Payload[2]) < (size - 2))
                            {   // decode the next value and move p_buffer accordingly
                                m_var = decode_variable(p_buffer);
                                p_buffer += m_var.size;
                                // take the update order into account
                                update_variable();
                            }
                            MiApp_DiscardMessage();
                            if (ack_required)
                            {   // all values decoded, answer if last_update
                                while (!send_writables_update())
                                {
                                    // failed attempt
                                    consecutive_fails++;
                                    if (consecutive_fails >= MAX_CONSECUTIVE_FAILS)
                                    {
                                        // sleep 1min: reset!
                                        myAppState = STATE_PROBLEM;
                                        LATCbits.LATC0 = 0;  // turn led off
                                        MiApp_TransceiverPowerState(POWER_STATE_SLEEP);
                                        timer_reset();
                                        PIR3bits.RTCCIF = 0;  // clear RTCC interrupt flag
                                        //OSCCONbits.IDLEN = 0;   // specs says it should be used just before SLEEP())
                                        SLEEP();    // now we are sleeping
                                        RESET();    // now we don't
                                    }
                                    wait_for_1_sec(); // or not ?
                                }
                                consecutive_fails = 0;
                                return true;
                            }
                        }
                        else
                            MiApp_DiscardMessage();

                    default:
                        MiApp_DiscardMessage();
                }
            }
        }
    }
    return result;   // will be false if timeout
}


void inline sleep_and_reset()
{
    LATCbits.LATC0 = 0;  // turn led off
    timer_reset();
    MiApp_TransceiverPowerState(POWER_STATE_SLEEP);
#ifdef SLEEPING_SCOUT
    while (!timer_flag)
    {
        OSCCONbits.IDLEN = 0;   // specs says it should be used just before SLEEP())
        SLEEP();        // now we are sleeping            
    }
#else
    while(!timer_flag)
    {}
#endif
    MiApp_TransceiverPowerState(POWER_STATE_WAKEUP);// wake up the MRF89
    RESET();    // it's groundhog day!
}


/* read the sensors values and update the corresponding variables */

void read_sensors()
{
    // measure the external voltage ref & the temperature
    ADCON0bits.ADON = 1;    // ADC is on - must be far from GO
    LATAbits.LATA6 = 1;     // turn on the output ref voltage+I2Ctemp supply
    __delay_ms(20);         // let it rise - use MRF89 waking up instead

    // start with a calibration, even after each sleep
    ADCON1bits.ADCAL = 1;   // calibration mode ON
    ADCON0bits.GO = 1;      // start the automatic acq+conversion
    while (ADCON0bits.GO == 1)  {}  // wait for the ADC to finish its job
    ADCON1bits.ADCAL = 0;   // calibration mode OFF

    // read the voltage ref
    ADCON0bits.CHS = 0;     // select AN0 for ADC        
    ADCON0bits.GO = 1;              // start the automatic acq+conversion
    while (ADCON0bits.GO == 1)  {}  // wait for the ADC to finish its job

    uint16_t adc_result = (ADRESHbits.ADRESH << 8) + ADRESLbits.ADRESL;
    m_battery_voltage = (4096F / adc_result) * 1.24F;

    // read the photodiode voltage
    ADCON0bits.CHS = 1;     // select AN1 for ADC
    //__delay_ms(10);
    ADCON0bits.GO = 1;              // start the automatic acq+conversion
    while (ADCON0bits.GO == 1)  {}  // wait for the ADC to finish its job

    adc_result = (ADRESHbits.ADRESH << 8) + ADRESLbits.ADRESL;  // 0 for absolute dark, 74 for full sunlight
    m_light_level = (uint8_t)((adc_result / 74F) * 100F); // as a percentage
    if (m_light_level > 100)
    {
        m_light_level = 100;
    }

    //int tmp=0;

    // read temp
    __delay_ms(90); // to let the sensor read the temp
    OpenI2C(MASTER, SLEW_OFF);

    uint8_t t0, t1;

    // ask for register #0
    IdleI2C();                         // Wait until the bus is idle
    StartI2C();                        // Send START condition
    IdleI2C();                         // Wait for the end of the START condition
    WriteI2C( temp_slave_address & 0xfe );  // Send address with R/W cleared for write
    IdleI2C();                         // Wait for ACK
    WriteI2C( 0x00 );                  // Write register pointer
    IdleI2C();                         // Wait for ACK
    StopI2C();                         // Hang up, send STOP condition

    // read register #0
    IdleI2C();                         // Wait until the bus is idle
    StartI2C();                        // Send START condition
    IdleI2C();                         // Wait for the end of the START condition
    WriteI2C( temp_slave_address | 0x01 );  // Send address with R/W set for read
    IdleI2C();                         // Wait for ACK
    t1 = ReadI2C();               // Read first byte of data
    AckI2C();                          // Send ACK
    t0 = ReadI2C();               // Read nth byte of data
    NotAckI2C();                       // Send NACK
    StopI2C();                         // Hang up, send STOP condition

    uint16_t value = (t1<<8) + t0;
    value = (value>>4);
    m_temperature = ((float)value)*0.0625F;

    ADCON0bits.ADON = 0;  // ADC is off
    CloseI2C();           // shutdown I2C
    LATAbits.LATA6 = 0;   // turn off the sensors power supply
}


/* send all the variables */
bool send_initial_update()
{
    uint16_t tmp;
    // FIRST PART OF THE UPDATE
    p_buffer = m_buffer;    // encode the variables/values in a temporary buffer
    // encode units variables/values now
    // send the battery voltage
    memcpy(m_var.label, BATTERY_VOLTAGE_LABEL, 3);
    m_var.unit = MUTA_VOLT_UNIT;
    m_var.value_byte1 = (uint8_t)floor(m_battery_voltage);  // integer part
    m_var.value_byte2 = (uint8_t)floor(((m_battery_voltage - floor(m_battery_voltage))*100));  // +2 digits
    m_var.writable = false;
    p_buffer += encode_ufixed16_variable(p_buffer, m_var);
    // send the light level
    memcpy(m_var.label, LIGHT_LEVEL_LABEL, 3);
    m_var.unit = MUTA_PERCENT_UNIT;
    m_var.value_byte1 = m_light_level;
    m_var.writable = false;
    p_buffer += encode_uint8_variable(p_buffer, m_var);
    // send the temperature
    memcpy(m_var.label, TEMPERATURE_LABEL, 3);
    m_var.unit = MUTA_DEGREES_UNIT;
    m_var.value_byte1 = (uint8_t)floor(m_temperature);  // integer part
    m_var.value_byte2 = (uint8_t)floor(((m_temperature - floor(m_temperature))*100));  // +2 digits
    m_var._signed = true;
    m_var.writable = false;
    p_buffer += encode_ufixed16_variable(p_buffer, m_var);
    // send the message
    if (!do_UPDATE(m_buffer, p_buffer-m_buffer, false))
        return false;

    // SECOND PART OF THE UPDATE
    p_buffer = m_buffer;    // encode the variables/values in a temporary buffer
    // send the power level
    memcpy(m_var.label, POWER_LABEL, 3);
    m_var.unit = MUTA_MWATT_UNIT;
    dBm_to_mW_ufixed16(m_power, &(m_var.value_byte1), &(m_var.value_byte2));
    m_var.writable = true;
    p_buffer += encode_ufixed16_variable(p_buffer, m_var);
    // send the uptime as a fraction of days
    memcpy(m_var.label, UPTIME_LABEL, 3);
    m_var.unit = MUTA_DAYS_UNIT;
    m_var.value_byte1 = (uint8_t)floor(m_uptime_days);  // integer part
    m_var.value_byte2 = (uint8_t)floor(((m_uptime_days - floor(m_uptime_days))*100));  // +2 digits
    m_var.writable = false;
    p_buffer += encode_ufixed16_variable(p_buffer, m_var);
    // send the update frequency
    memcpy(m_var.label, UPDATE_FREQUENCY_LABEL, 3);
    m_var.unit = MUTA_MINUTES_UNIT;
    m_var.value_byte1 = m_update_frequency;
    m_var.writable = true;
    p_buffer += encode_uint8_variable(p_buffer, m_var);
    // send the message
    if (!do_UPDATE(m_buffer, p_buffer-m_buffer, false))
        return false;
    
    // THIRD PART OF THE UPDATE
    // send the failed msg percentage
    p_buffer = m_buffer;    // encode the variables/values in a temporary buffer
    memcpy(m_var.label, FAILEDMSG_LABEL, 3);
    m_var.unit = MUTA_PERCENT_UNIT;
    float tmp2 = (float)(m_failed_messages*100)/(float)(m_failed_messages + m_sent_messages); // 33.33
    m_var.value_byte1 = (uint8_t)floor(tmp2);  // integer part
    m_var.value_byte2 = (uint8_t)floor(((tmp2 - floor(tmp2))*100));  // +2 digits
    m_var.writable = false;
    p_buffer += encode_ufixed16_variable(p_buffer, m_var);
    // send the message
    return do_UPDATE(m_buffer, p_buffer-m_buffer, true);
}
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

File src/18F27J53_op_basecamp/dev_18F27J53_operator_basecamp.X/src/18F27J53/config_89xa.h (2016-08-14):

/********************************************************************
 Software License Agreement:

 The software supplied herewith by Microchip Technology Incorporated
 (the "Company") for its PIC(R) Microcontroller is intended and
 supplied to you, the Company's customer, for use solely and
 exclusively on Microchip PIC Microcontroller products. The
 software is owned by the Company and/or its supplier, and is
 protected under applicable copyright laws. All rights are reserved.
 Any use in violation of the foregoing restrictions may subject the
 user to criminal sanctions under applicable laws, as well as to
 civil liability for the breach of the terms and conditions of this
 license.

 THIS SOFTWARE IS PROVIDED IN AN "AS IS" CONDITION. NO WARRANTIES,
 WHETHER EXPRESS, IMPLIED OR STATUTORY, INCLUDING, BUT NOT LIMITED
 TO, IMPLIED WARRANTIES OF MERCHANTABILITY AND FITNESS FOR A
 PARTICULAR PURPOSE APPLY TO THIS SOFTWARE. THE COMPANY SHALL NOT,
 IN ANY CIRCUMSTANCES, BE LIABLE FOR SPECIAL, INCIDENTAL OR
 CONSEQUENTIAL DAMAGES, FOR ANY REASON WHATSOEVER.
 *******************************************************************/

#ifndef __CONFIG_MRF89XA_H

    #define __CONFIG_MRF89XA_H
    

    /*********************************************************************/
    // BAND_902, BAND_915 or BAND_863 (or BAND_950 - circuit dependent) are three supported frequency
    // band for Microchip MRF89XA. One and only one of the frequency
    // band must be defined 
    /*********************************************************************/
    //#define BAND_902      //Choose BAND_902 and BAND_915 for FCC and IC
                            //Supports frequencies between 902 - 915MHz
    //#define BAND_915      //Supports frequencies between 915 - 928MHz

    #define BAND_863        //Choose this for Europe ETSI 868MHz Frequency band
                            //Supports frequencies between 863MHz - 870MHz
    
    /*********************************************************************/
    // DATA_RATE_5, DATA_RATE_10, DATA_RATE_20, 
    // DATA_RATE_25, DATA_RATE_40, DATA_RATE_50, DATA_RATE_66,
    // DATA_RATE_100 and DATA_RATE_200 are 10 data rates supported 
    // by Microchip MRF89XA transceivers in MiMAC interface. One and only 
    // one of the data rate must be defined
    /*********************************************************************/  
    //#define DATA_RATE_5
    //#define DATA_RATE_10
    #define DATA_RATE_20
    //#define DATA_RATE_40
    //#define DATA_RATE_50
    //#define DATA_RATE_66
    //#define DATA_RATE_100
    //#define DATA_RATE_200
	
    
    
    /*********************************************************************/
    // LNA_GAIN defines the internal IF gain for
    // MRF89XA transceiver.
    /*********************************************************************/
    #define LNA_GAIN        LNA_GAIN_0_DB
    
    /*********************************************************************/
    // TX_POWER defines the output power for MRF89XA
    /*********************************************************************/
    #define TX_POWER        TX_POWER_13_DB

/*
#define TX_POWER_13_DB      0x00    //[3:1], 13dBm  => 20mW (interdit en France)
#define TX_POWER_10_DB      0x01	//10dBm         => 10mW
#define TX_POWER_7_DB       0x02	//7dBm          => 5mW
#define TX_POWER_4_DB       0x03	//4dBm          => 2.5mW
#define TX_POWER_1_DB       0x04	//1dBm          => 1.2mW
#define TX_POWER_N_2_DB     0x05	//-2dBm         => 0.6mW
#define TX_POWER_N_5_DB     0x06	//-5dBm         => 0.3mW
#define TX_POWER_N_8_DB     0x07	//-8dBm         => 0.15mW
*/
// En France, sur la bande 863 - 870MHz, on peut émettre légalement à 15mW
// donc choisir 10dBm max
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

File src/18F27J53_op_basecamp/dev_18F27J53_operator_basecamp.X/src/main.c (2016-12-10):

/*
 * MUTA operator / basecamp - r2 (MUTA v01) - 12/2016
 * 
 * Main source code: copyright (2015-2016) Nicolas Barthe,
 * distributed as open source under the terms
 * of the GNU General Public License (see COPYING.txt)
 * 
 * USB and MIWI original source code: copyright Microchip.
 * 
*/

#include <xc.h>         // should compile with XC8 v1.35 + legacy PLIB v2.00
#include <stdint.h>     // remember: you must install manually legacy plib
#include <timers.h>     // since XC8 v1.35 doesn't include plib anymore
#include <pwm.h>
#include <math.h>
#include "18F27J53/system.h"
#include "18F27J53/system_config.h"
#include "18F27J53/symbol.h"
#include "usb_config.h"
#include "usb/usb.h"
#include "usb/usb_device_hid.h"
#include "app_led_usb_status.h"
#include "miwi/miwi_api.h"
#include "drv_mrf_miwi_89xa.h"
#include "../../../muta/muta_messages.h"

/* miwi config is configured through the following files:
      config_89xa.h: TX power, bitrate...
      miwi_config.h: Miwi role/options

the initial output power is determined statically
by the value of TX_POWER set in config_89xa.h.
Current config: 1dBm => 1.2mW

Remember: Miwi stack uses TIMER1
 + drv_mrf_miwi_89xa.c has been patched for the LED to reflect Miwi activity
 (see drv_mrf_miwi_89xa.c, line #1475) */

/* note: clock frequency and MK1/MK3 #define are in system_config.h */

/* config words start @0x01FFF8
let's put some const at the end of flash memory:
    model of the unit (00: operator, 01:scout, 02:enforcer...)
    + make of the unit (1 for mk1, 2 for mk2...) */
const uint8_t myMUTA_version @ 0x01FFF2 = 0x01; // MUTA protocol version
const uint8_t myMODEL @ 0x01FFF4 = 0x00; // operator
// Unique ID used to identify the unit
const uint8_t myUID[2] @ 0x01FFF6 = { 0x00, 0x01 }; // UID, must be unique!
extern uint8_t myLongAddress[4];    // equal to myMODEL+myUID
                                    // done at the beginning of main()
/* this is the 64bit key that will be used for encryption/decryption
!!!it should be the same for every unit!!!
algo: XTEA64 + CCM_16 */
const unsigned char StaticSecurityKey[8] @ 0x01FEC = { 0x00, 0x01, 0x02, 0x03, 0x04, 0x05, 0x06, 0x07  };
unsigned char mySecurityKey[8];
/* note: mySecurityKey will be initialized with StaticSecurityKey
 * then mySecurityKey[2] and mySecurityKey[6] will be replaced by
 * random values generated for each network session by the PC-side python script
 * and returned through NETWORK_REGISTER */

/* Memory mapping of myMODEL, myUID and mySecurityKey:
    myMODEL[2] @ 0x01FFF4
    myUID[2] @ 0x01FFF6
    mySecurityKey[8] @ 0x01FEC        
=> allow the use of HEXMATE (command line utility that comes with MPLABX)
to modify those value without recompiling the firmware
ex.: HEXMATE source.hex -FILL=0xBEEF@0x1000 -Odest.hex */

// Possible channel numbers are from 0 to 31
// channels 0,4,8,12,16,20,24,28 (energy scan duration: ~22sec)
#define MUTA_CHANNELS      0x11111111
//#define MUTA_CHANNELS      0x01010101   // channel 0,8,16,24 only
//#define MUTA_CHANNELS      0x00000001   // channel 0 only

// to use the internal RTCC as a timer (with frequency==multiples of 1min, default @1min)
#define DEFAULT_UPDATE_FREQUENCY    1
volatile bool timer_flag = false;
volatile uint8_t timer_count = DEFAULT_UPDATE_FREQUENCY;

// Dedicated Operator Variables / values
const char POWER_LABEL[] = "Pwr";   // Operator TX Power level
const char PANID_LABEL[] = "PAN";   // PANid associated with the operator
const char CHANNEL_LABEL[] = "Chn"; // Channel used by the operator
const char NOISE_LABEL[] = "Nse";   // Noise level measured on the channel
uint8_t m_power, noise_level, BestChannel;
const char UPTIME_LABEL[] = "Upt";  // Uptime (since the last reset)
volatile float m_uptime_days = 0;   // updated every minute
const char UPDATE_FREQUENCY_LABEL[] = "UpF";    // Update frequency
volatile uint8_t m_update_frequency = DEFAULT_UPDATE_FREQUENCY;
unsigned long m_failed_messages = 0;
unsigned long m_sent_messages = 0;

bool Pwr_updated = false;
bool UpF_updated = false;

// TinyPack encoding stuff
uint8_t m_buffer[32];
uint8_t * p_buffer;
MUTA_VARIABLE m_var;

// Main functions / helpers to keep the main code simple & clean
void timer_reset();
void RTCC_reset();
void send_network_register();
void send_complete_update();
void send_answer_to_update();
void send_periodic_update();
void update_variable();
void wait_for_1_sec();

// USB stuff
void APP_DeviceCustomHIDInitialize();
unsigned char ReceivedDataBuffer[64];
unsigned char ToSendDataBuffer[64];
unsigned char* pUsbBuffer;
bool sendHIDBinary(uint8_t* buffer, uint8_t length);   // send binary via USB
bool sendHIDText(char* str);                           // send text via USB
volatile USB_HANDLE USBOutHandle;
volatile USB_HANDLE USBInHandle;

// to make the led gently pulse (using PWM), instead of a raw blinking mode
#define LED_max_brightness  235
#define LED_min_brightness  10
volatile uint16_t LED_brightness = LED_max_brightness;
volatile uint8_t LED_increasing = 0;
typedef enum
{
    LED_OFF,
    LED_FAST_PULSE,
    LED_SLOW_PULSE,
    LED_FULL
} LED_STATE;
volatile LED_STATE   status_led;
void update_LED();
volatile uint8_t repeat_full;

APP_STATE   myAppState;     // to track USB states (from USB demo source code)
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

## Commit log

2016-08-13 source code comments
    [dev_18F27J53_operator_basecamp.X.production.obj, dev_18F27J53_operator_relay.X.production.obj, dev_18F27J53_scout_dormant.X.production.obj]
2016-08-14 minor fixes, now every unit emits at full power at startup, TODO list and README.md
    [dev_18F27J53_operator_basecamp.X.production.obj, dev_18F27J53_operator_relay.X.production.obj, dev_18F27J53_scout_dormant.X.production.obj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]
2016-12-04 operator updated for muta v01
    [dev_18F27J53_operator_basecamp.X.production.obj]
2016-12-09 muta v01 scout ok
    [dev_18F27J53_operator_basecamp.X.production.obj, dev_18F27J53_scout_dormant.X.production.obj]
2016-12-09 rtcc reset added
    [dev_18F27J53_operator_basecamp.X.production.obj, dev_18F27J53_scout_dormant.X.production.obj]
2016-12-10 cleaned all the sleep cycles for the scout
    [dev_18F27J53_operator_basecamp.X.production.obj, dev_18F27J53_scout_dormant.X.production.obj]
2016-12-29 fixed _signed bug for temp
    [dev_18F27J53_scout_dormant.X.production.obj]

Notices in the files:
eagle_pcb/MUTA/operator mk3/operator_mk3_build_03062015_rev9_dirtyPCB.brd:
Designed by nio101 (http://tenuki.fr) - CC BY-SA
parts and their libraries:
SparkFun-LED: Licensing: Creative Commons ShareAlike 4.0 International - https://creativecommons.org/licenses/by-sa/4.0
